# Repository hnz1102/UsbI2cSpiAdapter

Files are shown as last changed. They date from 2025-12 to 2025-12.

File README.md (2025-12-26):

# USB-I2C/SPI Adapter

<div align="center">
  <p>
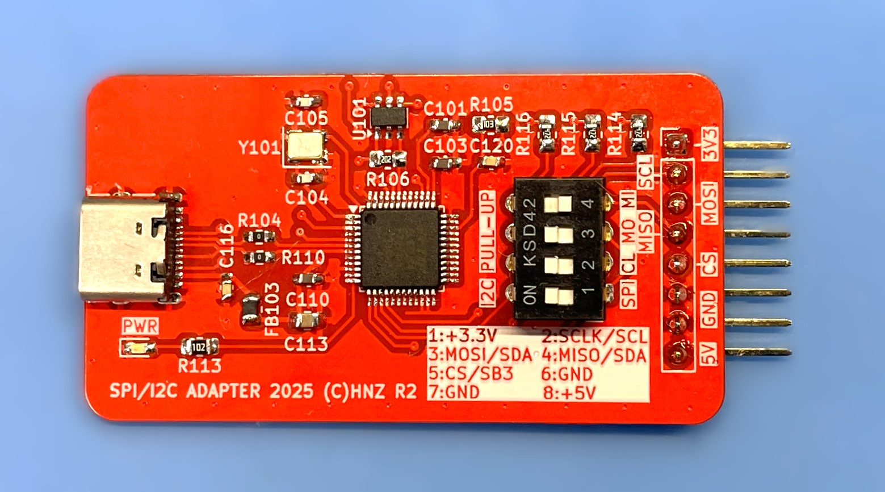
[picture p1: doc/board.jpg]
    
  </p>
</div>

## Overview

This directory contains the hardware design files for a USB-I2C/SPI adapter based on the FTDI FT232H chip. The adapter enables USB connectivity for I2C and SPI communication with various embedded devices and sensors.

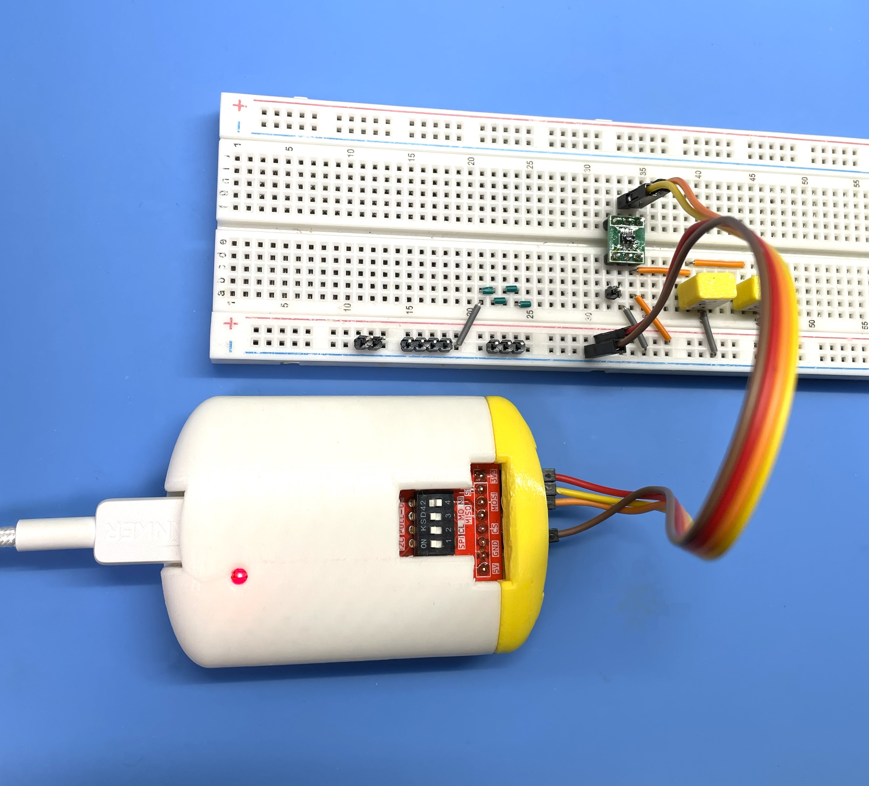
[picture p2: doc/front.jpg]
adapter


## Hardware Features

- **USB Interface**: USB 2.0 Full Speed (12 Mbps)
- **Main Controller**: FTDI FT232H (MPSSE capable)
- **Protocols Supported**: I2C, SPI, GPIO
- **USB-C Connector**: Modern USB Type-C connection
- **Operating Voltage**: 3.3V I/O (5V USB powered)
- **Compact Design**: Optimized PCB layout for ease of use

## Design Files

This repository includes the following KiCad project files:

| File | Description |
|---|---|
| `i2cmaster.kicad_sch` | Schematic design file |
| `i2cmaster.kicad_pcb` | PCB layout file |
| `i2cmaster.kicad_pro` | KiCad project file |
| `i2cmaster.csv` | Bill of Materials (BOM) |
| `fp-lib-table` | Footprint library table |
| `Library.pretty/` | Custom footprint library |

## 3D Model

A 3D model of the enclosure is available:

- `F3D/usbi2c.f3d` - Fusion 360 design file for the adapter enclosure

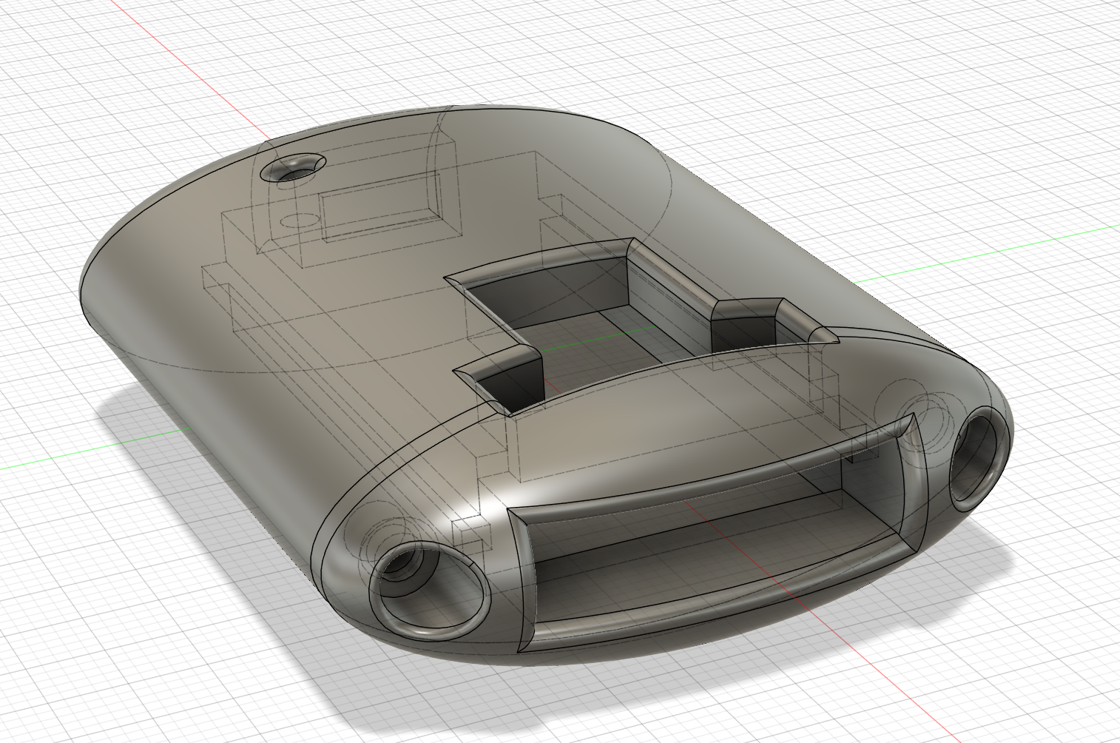
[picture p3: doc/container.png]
3dmodel


## Production Files

The `i2cmaster.kicad_pcb_gerber.zip` is Gerber files and production data for PCB manufacturing.

## Key Components

- **FT232H**: FTDI USB-to-MPSSE bridge chip
- **USB-C Connector**: 5077CR-16-SMC2-BK-TR (USB Type-C receptacle)
- **Voltage Regulator**: 3.3V LDO for I/O interface
- **ESD Protection**: Protection circuitry for USB lines
- **Pull-up Resistors**: I2C bus pull-up resistors (typically 4.7kΩ)

## Pin Configuration

The adapter connector has the following pin assignments:

| Pin | Signal | Description |
|-----|---|---|
| 1 | +3.3V | 3.3V power output (limited current) |
| 2 | SCLK/SCL | SPI Clock / I2C Clock |
| 3 | MOSI/SDA | SPI Master Out / I2C Data (OUT in I2C mode) |
| 4 | MISO/SDA | SPI Master In / I2C Data (IN in I2C mode) |
| 5 | CS/DB3 | SPI Chip Select / GPIO DB3 |
| 6 | GND | Ground |
| 7 | GND | Ground |
| 8 | +5V | 5V power output (limited current) |

## DIP Switch Configuration

The adapter includes DIP switches to configure operation mode and pull-up resistors:

| Switch | Position | Function |
|---|---|---|
| S1 | ON | I2C mode (PIN3 and PIN4 connected, PIN3=OUT, PIN4=IN) |
| S1 | OFF | SPI mode (separate MOSI/MISO signals) |
| S2 | ON | SCLK/SCL pull-up resistor enabled |
| S3 | ON | MOSI/SDA pull-up resistor enabled |
| S4 | ON | MISO/SDA pull-up resistor enabled |

**Note**: When S1 is ON (I2C mode), PIN3 and PIN4 are internally connected to form a bidirectional SDA line, with PIN3 functioning as output and PIN4 as input.

## Software Compatibility

This hardware design is compatible with:

- FTDI D2XX drivers (Windows/Linux/macOS)
- libFTDI (open-source alternative)
- Custom applications using MPSSE commands
- Windows GUI application (see [UsbI2cController](https://github.com/hnz1102/UsbI2cController) for software documentation)

## Design Tools

- **KiCad 9.x or later**: PCB design and schematic capture
- **KiCad EDA**: Free and open-source electronics design automation suite

## Opening the Project

1. Install [KiCad](https://www.kicad.org/) (version 9.0 or later recommended)
2. Open the project file: `i2cmaster.kicad_pro`
3. Schematic: Double-click `i2cmaster.kicad_sch`
4. PCB Layout: Double-click `i2cmaster.kicad_pcb`

## Manufacturing

### PCB Specifications

- **Layers**: 2-layer PCB
- **Board Thickness**: 1.6mm (standard)
- **Copper Weight**: 1 oz (35 μm)
- **Surface Finish**: HASL
- **Solder Mask**: Red (or custom color)
- **Silkscreen**: White

## Electrical Characteristics

- **USB Power Input**: 5V ± 5%
- **I/O Voltage Level**: 3.3V CMOS
- **Maximum I/O Current**: Refer to FT232H datasheet
- **I2C Clock Speed**: Up to 400 kHz (Fast Mode) or 3.4 MHz (High-Speed Mode)
- **SPI Clock Speed**: Up to 30 MHz

## License

This Hardware Schematic documents are licensed under CC-BY-SA V4.0.

## References

- [FTDI FT232H Datasheet](https://ftdichip.com/wp-content/uploads/2020/07/DS_FT232H.pdf)
- [FTDI Application Notes](https://ftdichip.com/document/application-notes/)
- [KiCad Documentation](https://docs.kicad.org/)

## Changelog

- **2025-12-26**: Initial hardware design with USB-C connector
- Production files generated for PCB manufacturing

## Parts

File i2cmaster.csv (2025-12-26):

Reference | Qty | Value | DNP | Exclude from BOM | Exclude from Board | Footprint | digikey
C101,C102,C103,C106,C107,C108,C110,C111,C112,C118 | 10 | 0.1uF |  |  |  | Capacitor_SMD:C_0603_1608Metric | 311-1343-1-ND
C104,C105 | 2 | 27pF |  |  |  | Capacitor_SMD:C_0603_1608Metric | 311-1063-1-ND
C113,C114,C115,C119 | 4 | 4.7uF |  |  |  | Capacitor_SMD:C_0805_2012Metric | 490-10751-1-ND
C116,C120 | 2 | 0.01uF |  |  |  | Capacitor_SMD:C_0603_1608Metric | 399-C0603C103K5RACTUCT-ND
D101 | 1 | LED RED |  |  |  | LED_SMD:LED_0603_1608Metric | 3147-B1931URO-20D000114U1930CT-ND
FB101,FB102,FB103 | 3 | BK2125HS601-T |  |  |  | Inductor_SMD:L_0805_2012Metric_Pad1.15x1.40mm_HandSolder | MH2029-601YCT-ND
J101 | 1 | USB4105-GF-A |  |  |  | Library:USB_C_5077CR-16-SMC2-BK-TR | 2073-USB4105-GF-ACT-ND
J102 | 1 | PinHeader Conn_01x08 |  |  |  | Connector_PinHeader_2.54mm:PinHeader_1x08_P2.54mm_Vertical | 10129379-908001BLF-ND
R101 | 1 | 12K 1% |  |  |  | Resistor_SMD:R_0603_1608Metric | 13-RC0603FR-1312KLCT-ND
R102,R103,R105,R107 | 4 | 10K |  |  |  | Resistor_SMD:R_0603_1608Metric | 13-RC0603JR-1010KLCT-ND
R106 | 1 | 2K |  |  |  | Resistor_SMD:R_0603_1608Metric | 311-2.00KHRCT-ND
R108,R109 | 2 | 5.1K |  |  |  | Resistor_SMD:R_0603_1608Metric | 311-5.10KHRCT-ND
R113 | 1 | 1K |  |  |  | Resistor_SMD:R_0603_1608Metric | 13-RC0603JR-1010KLCT-ND
R114,R115,R116 | 3 | 4K7 |  |  |  | Resistor_SMD:R_0603_1608Metric | 311-4.70KHRCT-ND
SW1 | 1 | SW_DIP_x04 |  |  |  | Button_Switch_THT:SW_DIP_SPSTx04_Slide_6.7x11.72mm_W7.62mm_P2.54mm_LowProfile | CT2104MS-ND
U101 | 1 | 93LC56BT-I/OT |  |  |  | Package_TO_SOT_SMD:SOT-23-6 | 93LC56BT-I/OTCT-ND
U102 | 1 | FT232HL |  |  |  | Package_QFP:LQFP-48_7x7mm_P0.5mm | 768-1101-1-ND
Y101 | 1 | 12MHz |  |  |  | Crystal:Crystal_SMD_3225-4Pin_3.2x2.5mm | 535-ABM8-272-T3CT-ND

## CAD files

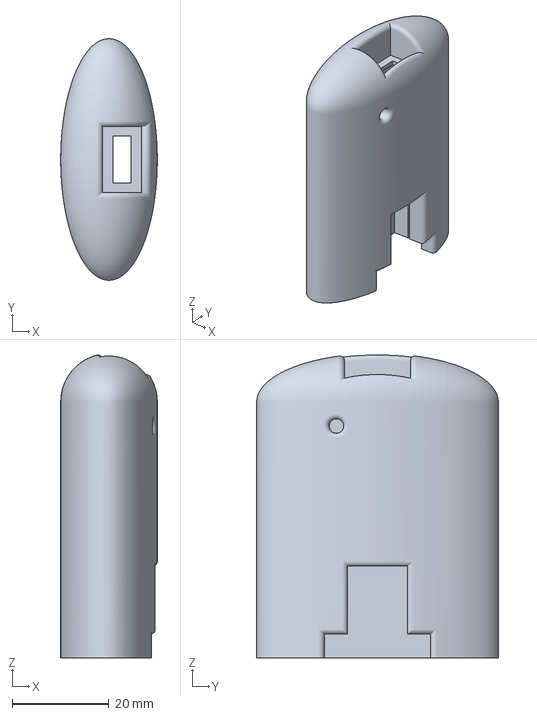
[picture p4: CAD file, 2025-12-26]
F3D/leftbody.3mf
20.0 x 50.0 x 62.7 mm

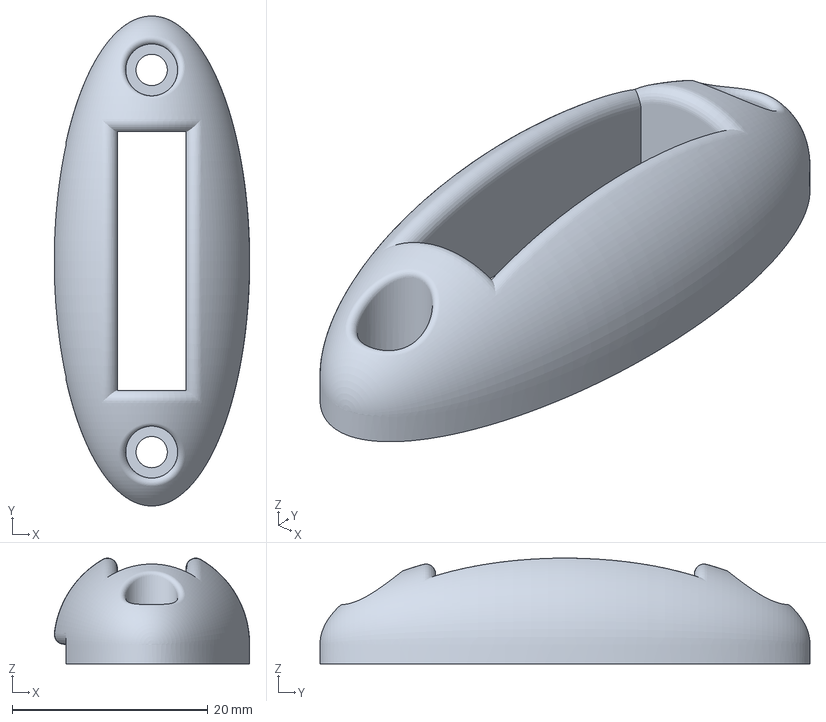
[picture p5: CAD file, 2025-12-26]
F3D/rightbody.3mf
19.9 x 50.0 x 10.8 mm

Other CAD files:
F3D/usbi2c.f3d

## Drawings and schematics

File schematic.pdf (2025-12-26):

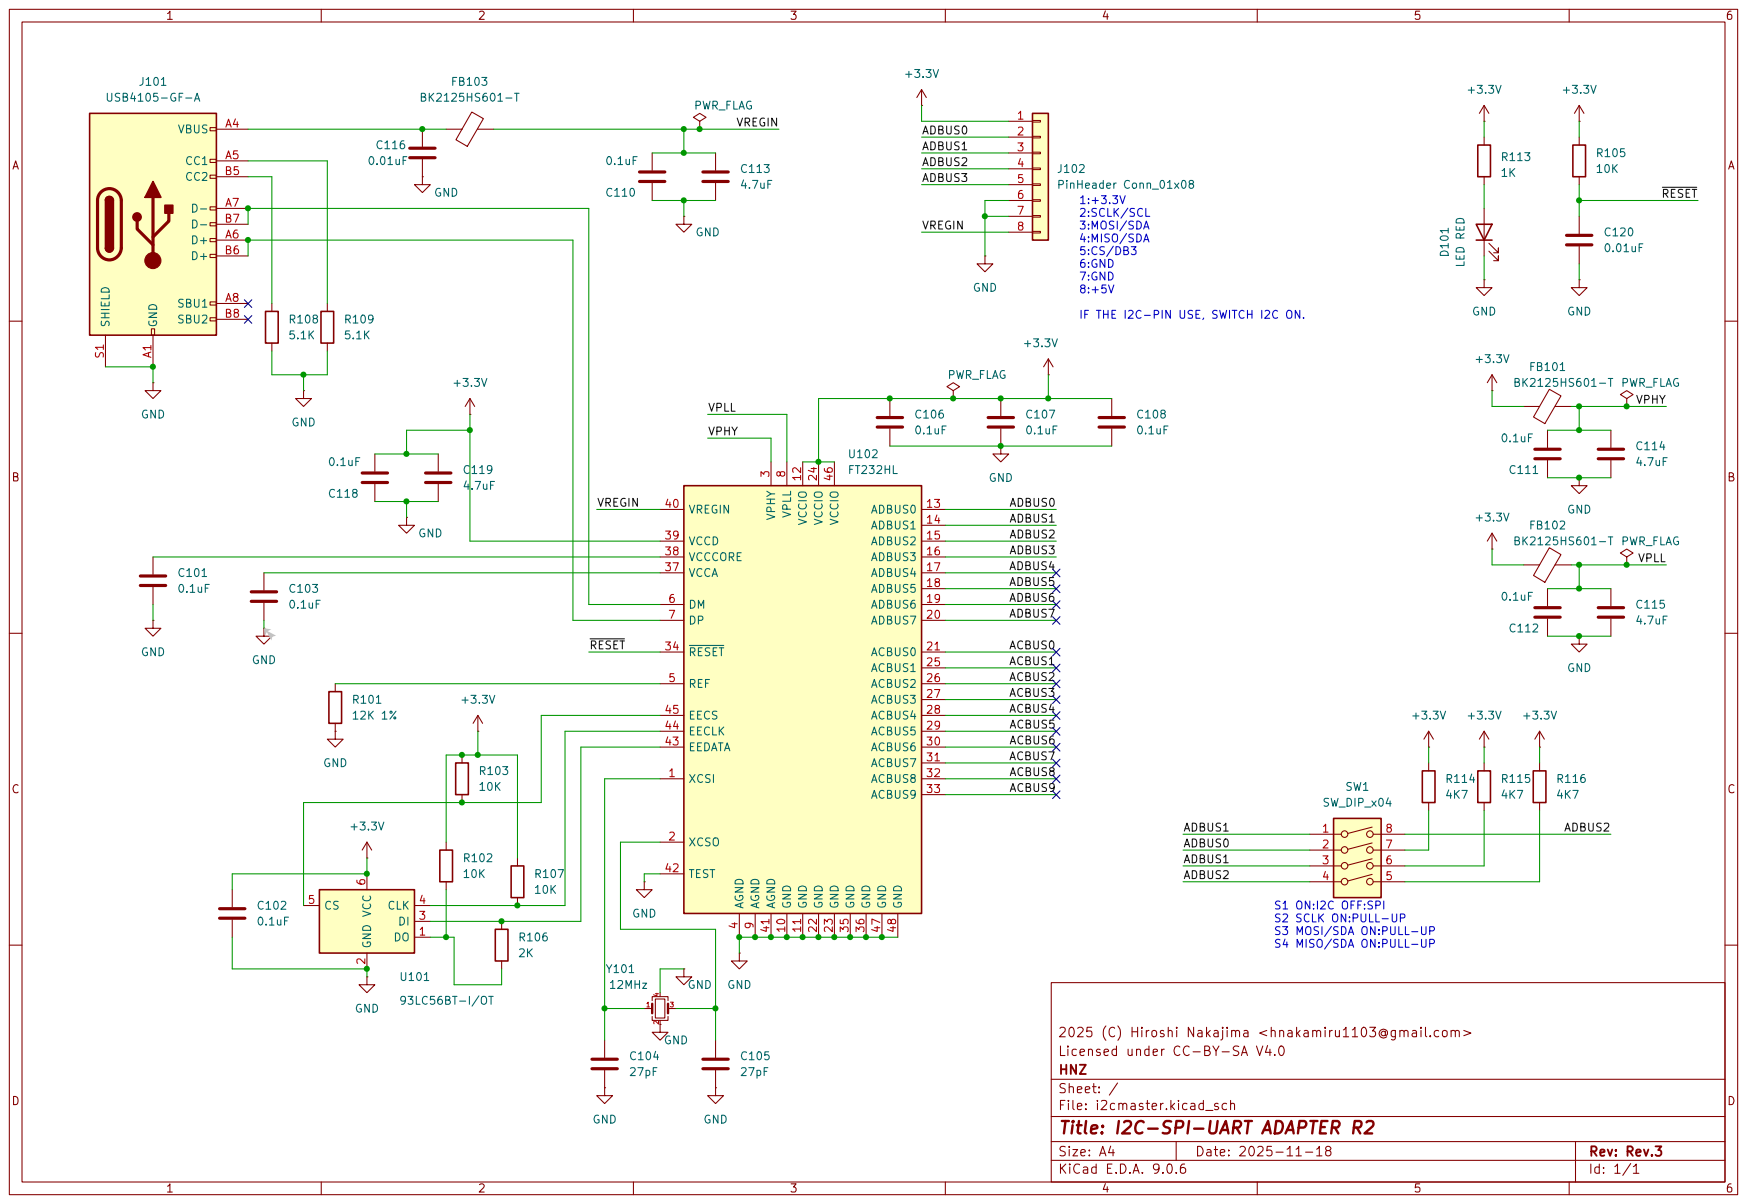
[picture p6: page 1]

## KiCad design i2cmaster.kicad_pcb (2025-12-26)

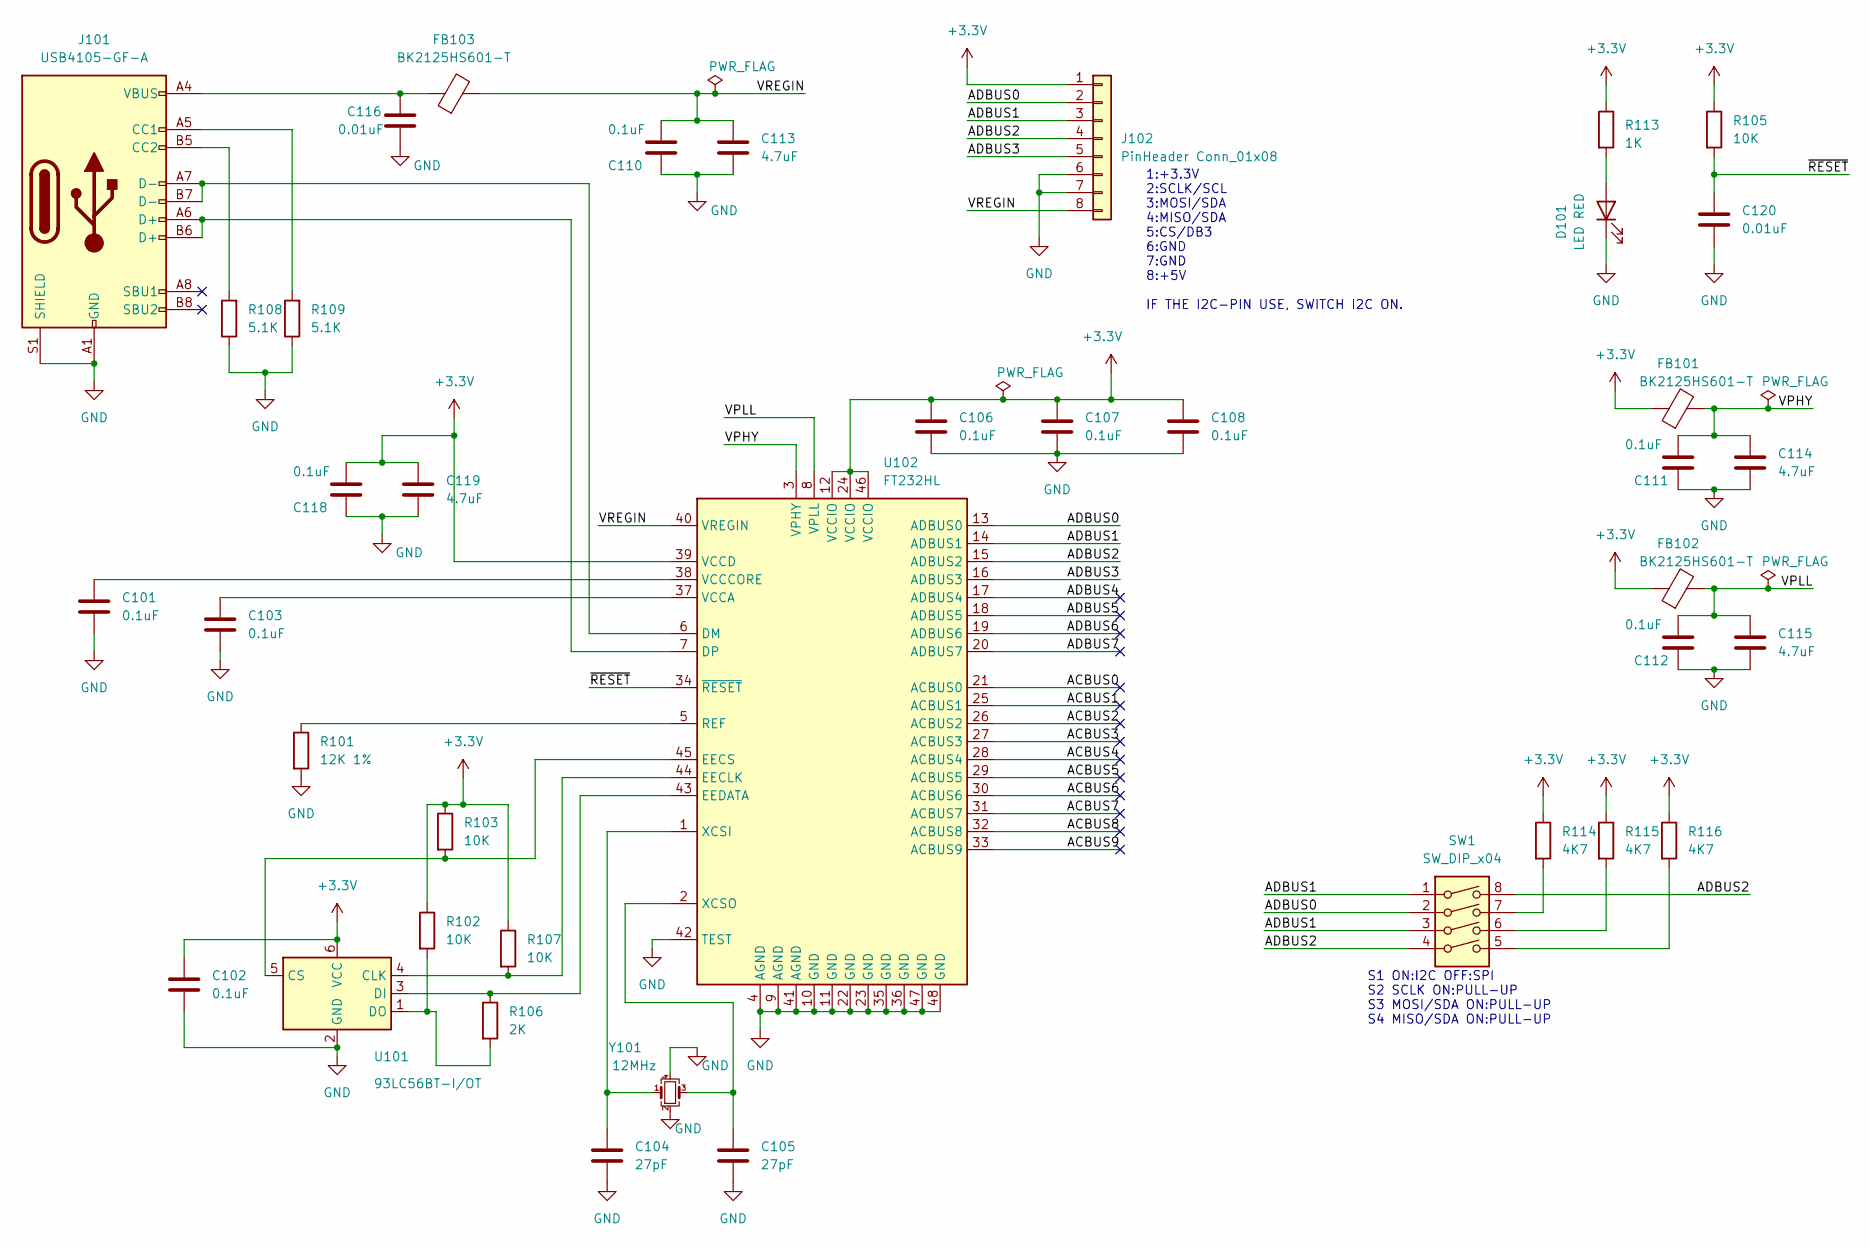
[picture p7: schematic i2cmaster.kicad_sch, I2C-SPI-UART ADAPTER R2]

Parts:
C101, C102, C103, C106, C107, C108, C110, C111, C112, C118: 0.1uF; C_0603_1608Metric; digikey 311-1343-1-ND
C104, C105: 27pF; C_0603_1608Metric; digikey 311-1063-1-ND
C113, C114, C115, C119: 4.7uF; C_0805_2012Metric; digikey 490-10751-1-ND
C116, C120: 0.01uF; C_0603_1608Metric; digikey 399-C0603C103K5RACTUCT-ND
D101: LED RED; LED_0603_1608Metric; digikey 3147-B1931URO-20D000114U1930CT-ND
FB101, FB102, FB103: BK2125HS601-T; L_0805_2012Metric_Pad1.15x1.40mm_HandSolder; digikey MH2029-601YCT-ND
J101: USB4105-GF-A; USB_C_5077CR-16-SMC2-BK-TR; digikey 2073-USB4105-GF-ACT-ND
J102: PinHeader Conn_01x08; PinHeader_1x08_P2.54mm_Vertical; digikey 10129379-908001BLF-ND
R101: 12K 1%; R_0603_1608Metric; digikey 13-RC0603FR-1312KLCT-ND
R102, R103, R105, R107: 10K; R_0603_1608Metric; digikey 13-RC0603JR-1010KLCT-ND
R106: 2K; R_0603_1608Metric; digikey 311-2.00KHRCT-ND
R108, R109: 5.1K; R_0603_1608Metric; digikey 311-5.10KHRCT-ND
R113: 1K; R_0603_1608Metric; digikey 13-RC0603JR-1010KLCT-ND
R114, R115, R116: 4K7; R_0603_1608Metric; digikey 311-4.70KHRCT-ND
SW1: SW_DIP_x04; SW_DIP_SPSTx04_Slide_6.7x11.72mm_W7.62mm_P2.54mm_LowProfile; digikey CT2104MS-ND
U101: 93LC56BT-I/OT; SOT-23-6; digikey 93LC56BT-I/OTCT-ND
U102: FT232HL; LQFP-48_7x7mm_P0.5mm; digikey 768-1101-1-ND
Y101: 12MHz; Crystal_SMD_3225-4Pin_3.2x2.5mm; digikey 535-ABM8-272-T3CT-ND

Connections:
+3.3V: C102.1, C106.1, C107.1, C108.1, C118.1, C119.1, FB101.1, FB102.1, J102.1, R102.1, R103.1, R105.1, R107.1, R113.1, R114.1, R115.1, R116.1, U101.6 (VCC), U102.12 (VCCIO), U102.24 (VCCIO), U102.39 (VCCD), U102.46 (VCCIO)
/ACBUS0: U102.21 (ACBUS0)
/ACBUS1: U102.25 (ACBUS1)
/ACBUS2: U102.26 (ACBUS2)
/ACBUS3: U102.27 (ACBUS3)
/ACBUS4: U102.28 (ACBUS4)
/ACBUS5: U102.29 (ACBUS5)
/ACBUS6: U102.30 (ACBUS6)
/ACBUS7: U102.31 (ACBUS7)
/ACBUS8: U102.32 (ACBUS8)
/ACBUS9: U102.33 (ACBUS9)
/ADBUS0: J102.2, SW1.2, U102.13 (ADBUS0)
/ADBUS1: J102.3, SW1.1, SW1.3, U102.14 (ADBUS1)
/ADBUS2: J102.4, SW1.4, SW1.8, U102.15 (ADBUS2)
/ADBUS3: J102.5, U102.16 (ADBUS3)
/ADBUS4: U102.17 (ADBUS4)
/ADBUS5: U102.18 (ADBUS5)
/ADBUS6: U102.19 (ADBUS6)
/ADBUS7: U102.20 (ADBUS7)
/VPHY: C111.1, C114.1, FB101.2, U102.3 (VPHY)
/VPLL: C112.1, C115.1, FB102.2, U102.8 (VPLL)
/VREGIN: C110.1, C113.1, FB103.2, J102.8, U102.40 (VREGIN)
/~RESET: C120.1, R105.2, U102.34 (~RESET)
GND: C101.2, C102.2, C103.2, C104.2, C105.2, C106.2, C107.2, C108.2, C110.2, C111.2, C112.2, C113.2, C114.2, C115.2, C116.2, C118.2, C119.2, C120.2, D101.1 (K), J101.A1 (GND), J101.A12 (GND), J101.B1 (GND), J101.B12 (GND), J101.S1 (SHIELD), J102.6, J102.7, R101.2, R108.1, R109.1, U101.2 (GND), U102.4 (AGND), U102.9 (AGND), U102.10 (GND), U102.11 (GND), U102.22 (GND), U102.23 (GND), U102.35 (GND), U102.36 (GND), U102.41 (AGND), U102.42 (TEST), U102.47 (GND), U102.48 (GND), Y101.2, Y101.4
unnamed: C116.1, FB103.1, J101.A4 (VBUS), J101.A9 (VBUS), J101.B4 (VBUS), J101.B9 (VBUS)
unnamed: D101.2 (A), R113.2
unnamed: J101.A5 (CC1), R109.2
unnamed: J101.B5 (CC2), R108.2
unnamed: R114.2, SW1.7
unnamed: R115.2, SW1.6
unnamed: R116.2, SW1.5
unnamed: R107.2, U101.4 (CLK), U102.44 (EECLK)
unnamed: R103.2, U101.5 (CS), U102.45 (EECS)
unnamed: R106.1, U101.3 (DI), U102.43 (EEDATA)
unnamed: R102.2, R106.2, U101.1 (DO)
unnamed: J101.A7 (D-), J101.B7 (D-), U102.6 (DM)
unnamed: J101.A6 (D+), J101.B6 (D+), U102.7 (DP)
unnamed: R101.1, U102.5 (REF)
unnamed: C103.1, U102.37 (VCCA)
unnamed: C101.1, U102.38 (VCCCORE)
unnamed: C104.1, U102.1 (XCSI), Y101.1
unnamed: C105.1, U102.2 (XCSO), Y101.3

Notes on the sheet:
1:+3.3V 2:SCLK/SCL 3:MOSI/SDA 4:MISO/SDA 5:CS/DB3 6:GND 7:GND 8:+5V IF THE I2C-PIN USE, SWITCH I2C ON.
S1 ON:I2C OFF:SPI S2 SCLK ON:PULL-UP S3 MOSI/SDA ON:PULL-UP S4 MISO/SDA ON:PULL-UP

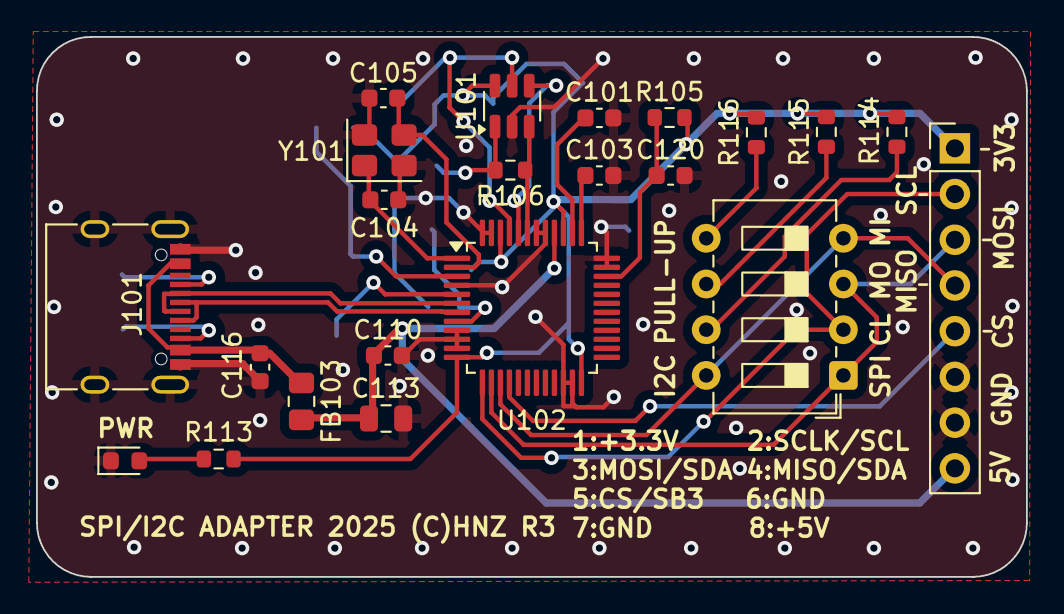
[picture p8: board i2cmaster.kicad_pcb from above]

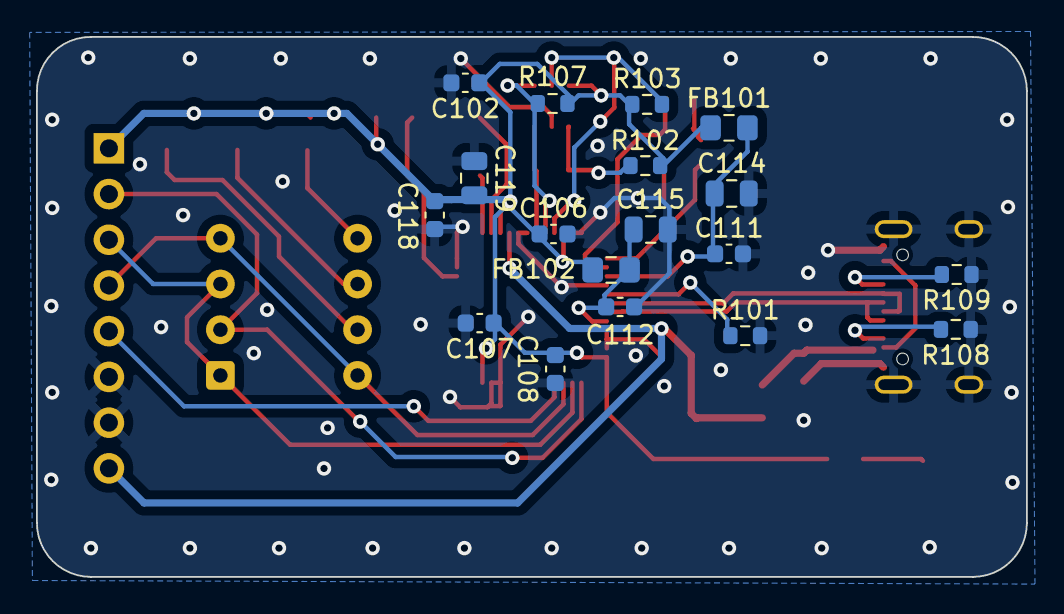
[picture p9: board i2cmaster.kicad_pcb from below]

Board: 2 copper layers, 55.0 x 30.0 mm, 40 parts (18 on the bottom side), 28 nets.

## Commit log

2025-12-26 Add enclosure data
    [usbi2c.f3d]
2025-12-26 Add 3MF files
    [leftbody.3mf, rightbody.3mf]
